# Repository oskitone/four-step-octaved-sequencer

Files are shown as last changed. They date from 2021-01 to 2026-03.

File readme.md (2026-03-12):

# Four-Step Octaved Sequencer

As featured in the blog post ["Prototype Post-Mortem: Four-Step Octaved Sequencer"](https://blog.tommy.sh/posts/prototype-post-mortem-four-step-octaved-sequencer/), these are the prototype PCB designs for a (yet to be totally finished) fun little noise toy.

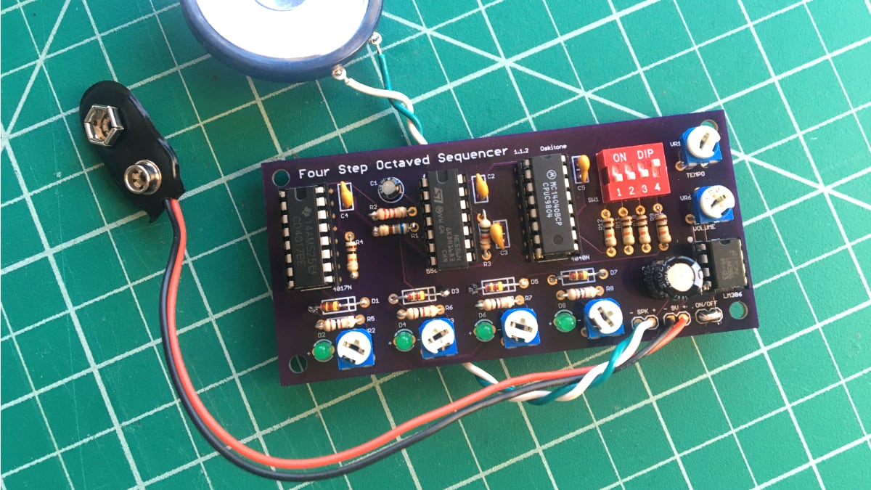
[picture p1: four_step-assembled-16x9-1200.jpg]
Four-Step Octaved Sequencer PCB assembled


The PCB and its electronics are possibly available as a [DIY electronics kit](https://www.oskitone.com/product/four-step-octaved-sequencer-kit). This repo serves as the assembly guide for the kit, as well as the EAGLE project so you can fabricate your own from scratch, should you want to!

**Demo video:** [https://vimeo.com/501110534](https://vimeo.com/501110534)  
**Order a PCB from OSH Park:** [https://oshpark.com/shared_projects/xo5nRkSm](https://oshpark.com/shared_projects/xo5nRkSm)

## Assembly guide

### Schematic

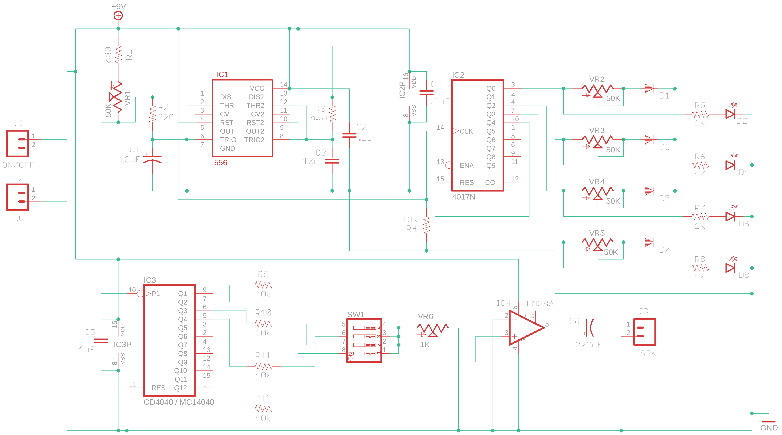
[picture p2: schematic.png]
Four Step Octaved Sequencer


### Annotated BOM

| Part | Value | Device | Marking | Purpose |
| ---- | --- | --- | --- | --- |
| C1 | 10uF | Polarized, electrolytic capacitor | | Tempo timer |
| C2 | .1uF | Ceramic capacitor | 104 | 556 IC bypass |
| C3 | 10nF | Ceramic capacitor | 103 | Pitch timer |
| C4 | .1uF | Ceramic capacitor | 104 | 4017 IC bypass |
| C5 | .1uF | Ceramic capacitor | 104 | 4040 IC bypass |
| C6 | 220uF | Polarized, electrolytic capacitor | | Amplifier |
| D1 | | Diode | | Step 1 output |
| D2 | | LED | | Step 1 indicator |
| D3 | | Diode | | Step 2 output |
| D4 | | LED | | Step 2 indicator |
| D5 | | Diode | | Step 3 output |
| D6 | | LED | | Step 3 indicator |
| D7 | | Diode | | Step 4 output |
| D8 | | LED | | Step 4 indicator |
| IC1  | 556 | 556 Dual 555 timer | | Timers for tempo (on left) and pitch (on right) |
| IC2  | 4017 | 4017 counter/divider | | Decade counter for steps |
| IC3  | 4040 | CD4040 or MC14040, 12-stage binary/ripple counter | | Divides pitch frequency into octaves |
| IC4  | 386 | LM386, low voltage audio power amplifier | | Amplifier |
| J1 | ON/OFF  | Header connection | | For external switch (not included) |
| J2 | - 9V +  | Header connection | | 9v battery snap |
| J3 | - SPK + | Header connection | | To 8ohm speaker |
| R1 | 680 | Resistor | Blue Grey Brown | Max tempo |
| R2 | 220 | Resistor | Red Red Brown | Tempo timer |
| R3 | 5.6k | Resistor | Green Blue Red | Pitch timer |
| R4 | 10k | Resistor | Brown Black Orange | Counter pulldown |
| R5 | 1K | Resistor | Brown Black Red | For step 1 LED |
| R6 | 1K | Resistor | Brown Black Red | For step 2 LED |
| R7 | 1K | Resistor | Brown Black Red | For step 3 LED |
| R8 | 1K | Resistor | Brown Black Red | For step 4 LED |
| R9 | 10k | Resistor | Brown Black Orange | Mixer for octave 1 |
| R10  | 10k | Resistor | Brown Black Orange | Mixer for octave 2 |
| R11  | 10k | Resistor | Brown Black Orange | Mixer for octave 3 |
| R12  | 10k | Resistor | Brown Black Orange | Mixer for octave 4 |
| SW1  | | 4 position SPST DIP Switch | | Octave mutes |
| VR1  | 50K | Variable resistor | 503 | Tempo |
| VR2  | 50K | Variable resistor | 503 | Step 1 pitch |
| VR3  | 50K | Variable resistor | 503 | Step 2 pitch |
| VR4  | 50K | Variable resistor | 503 | Step 3 pitch |
| VR5  | 50K | Variable resistor | 503 | Step 4 pitch |
| VR6  | 1K | Variable resistor | 102 | Volume |

Notes:

- Be sure to match polarity on electrolytic caps, diodes, and LEDs! The longer leg of the LED is positive
- The four ICs don't solder directly to the PCB. Instead, solder the included sockets, then insert ICs.
- IC3 may be marked as either CD4040 or MC14040. The two models are pin-for-pin compatible.
- The J1 (on/off) header is included for convenience if you have a switch you'd like to use. If not, short the two pads together.

### Hacking

All done? Try these ideas:

- Swap out for a bigger speaker to really hear the bass
- Increase gain on the [386](https://www.ti.com/lit/ds/symlink/lm386.pdf) with a 10uF cap between pins 1 and 8
- Try bigger pots for the step tuners
- Increase R1 for reaaalllly looongggg steeeppsssssssss
- Swap R9-12 with pots to get individual volume controls for each octave as they mix together
- The [4040](https://www.ti.com/lit/ds/symlink/cd4040b.pdf) has 12 "octave" outputs but we're only using four...

## Known issues

This PCB was last updated April 2018. In addition to the issues from the [post-mortem](https://blog.tommy.sh/posts/prototype-post-mortem-four-step-octaved-sequencer/):

- Some footprints are slightly mis-sized and require bending leads
- Volume control is linear instead of logarithmic, so range sweep isn't great
- Battery and speaker wires need relief holes to prevent breakage over time

## Version log

- **1.1.2**: Adds IC, header, and polarity labels; reorders octaves
- **1.1.1**: Adds mounting screw holes and a header for on/off switch (not included)
- **1.1**: Initial version featured in the blog post

## License

Designed by Oskitone. Please support future synth projects by purchasing from [Oskitone](https://www.oskitone.com/).

Creative Commons Attribution/Share-Alike, all text above must be included in any redistribution. See license.txt for additional details.

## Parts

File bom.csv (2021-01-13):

Part | Value | Device | Package | Description | PROD_ID | VALUE
C1 | 10uF | 10UF-POLAR-RADIAL-2.5MM-25V-20% | CPOL-RADIAL-2.5MM-5MM | 10.0µF polarized capacitors | CAP-08440 | 10uF
C2 | .1uF | 0.1UF-KIT-EZ-50V-20% | CAP-PTH-SMALL-KIT | 0.1µF ceramic capacitors | CAP-08370 | 0.1uF
C3 | 10nF | 0.1UF-KIT-EZ-50V-20% | CAP-PTH-SMALL-KIT | 0.1µF ceramic capacitors | CAP-08370 | 0.1uF
C4 | .1uF | 0.1UF-KIT-EZ-50V-20% | CAP-PTH-SMALL-KIT | 0.1µF ceramic capacitors | CAP-08370 | 0.1uF
C5 | .1uF | 0.1UF-KIT-EZ-50V-20% | CAP-PTH-SMALL-KIT | 0.1µF ceramic capacitors | CAP-08370 | 0.1uF
C6 | 220uF | 10UF-POLAR-RADIAL-2.5MM-25V-20% | CPOL-RADIAL-2.5MM-5MM | 10.0µF polarized capacitors | CAP-08440 | 10uF
D1 |  | DIODE-PTH | DIODE-1N4001 | Diode | DIO-09176 | 1A/50V/1.1V
D2 |  | LED3MM | LED_3MM | LED (Generic) | DIO-08794
D3 |  | DIODE-PTH | DIODE-1N4001 | Diode | DIO-09176 | 1A/50V/1.1V
D4 |  | LED3MM | LED_3MM | LED (Generic) | DIO-08794
D5 |  | DIODE-PTH | DIODE-1N4001 | Diode | DIO-09176 | 1A/50V/1.1V
D6 |  | LED3MM | LED_3MM | LED (Generic) | DIO-08794
D7 |  | DIODE-PTH | DIODE-1N4001 | Diode | DIO-09176 | 1A/50V/1.1V
D8 |  | LED3MM | LED_3MM | LED (Generic) | DIO-08794
IC1 | 556 | 556 | DIP14 | 556 Dual 555 timer | IC-11898 | 556
IC2 | 4017N | 4017N | DIL16 | COUNTER/DIVIDER
IC3 | CD4040 / MC14040 | 4040N | DIL16 | 12-stage binary/ripple COUNTER
IC4 | LM386 | LM386 | DIP08 | low voltage audio power amplifier | IC-10899 | LM386N
J1 | ON/OFF | CONN_02 | 1X02 | Multi connection point. Often used as Generic Header-pin footprint for 0.1 inch spaced/style header connections
J2 | - 9V + | CONN_02 | 1X02 | Multi connection point. Often used as Generic Header-pin footprint for 0.1 inch spaced/style header connections
J3 | - SPK + | CONN_02 | 1X02 | Multi connection point. Often used as Generic Header-pin footprint for 0.1 inch spaced/style header connections
R1 | 680 | 1KOHM-HORIZ-1/4W-1% | AXIAL-0.3 | 1kΩ resistor | RES-12182 | 1k
R2 | 220 | 1KOHM-HORIZ-1/4W-1% | AXIAL-0.3 | 1kΩ resistor | RES-12182 | 1k
R3 | 5.6K | 1KOHM-HORIZ-1/4W-1% | AXIAL-0.3 | 1kΩ resistor | RES-12182 | 1k
R4 | 10K | 1KOHM-HORIZ-1/4W-1% | AXIAL-0.3 | 1kΩ resistor | RES-12182 | 1k
R5 | 1K | 1KOHM-HORIZ-1/4W-1% | AXIAL-0.3 | 1kΩ resistor | RES-12182 | 1k
R6 | 1K | 1KOHM-HORIZ-1/4W-1% | AXIAL-0.3 | 1kΩ resistor | RES-12182 | 1k
R7 | 1K | 1KOHM-HORIZ-1/4W-1% | AXIAL-0.3 | 1kΩ resistor | RES-12182 | 1k
R8 | 1K | 1KOHM-HORIZ-1/4W-1% | AXIAL-0.3 | 1kΩ resistor | RES-12182 | 1k
R9 | 10k | 1KOHM-HORIZ-1/4W-1% | AXIAL-0.3 | 1kΩ resistor | RES-12182 | 1k
R10 | 10k | 1KOHM-HORIZ-1/4W-1% | AXIAL-0.3 | 1kΩ resistor | RES-12182 | 1k
R11 | 10k | 1KOHM-HORIZ-1/4W-1% | AXIAL-0.3 | 1kΩ resistor | RES-12182 | 1k
R12 | 10k | 1KOHM-HORIZ-1/4W-1% | AXIAL-0.3 | 1kΩ resistor | RES-12182 | 1k
SW1 |  | SW_DIP-4 | EDG-04 | DIP SWITCH
VR1 | 50K | POTTRIM | TRIM_POT |  | COM-00104
VR2 | 50K | POTTRIM | TRIM_POT |  | COM-00104
VR3 | 50K | POTTRIM | TRIM_POT |  | COM-00104
VR4 | 50K | POTTRIM | TRIM_POT |  | COM-00104
VR5 | 50K | POTTRIM | TRIM_POT |  | COM-00104
VR6 | 1K | POTTRIM | TRIM_POT |  | COM-00104

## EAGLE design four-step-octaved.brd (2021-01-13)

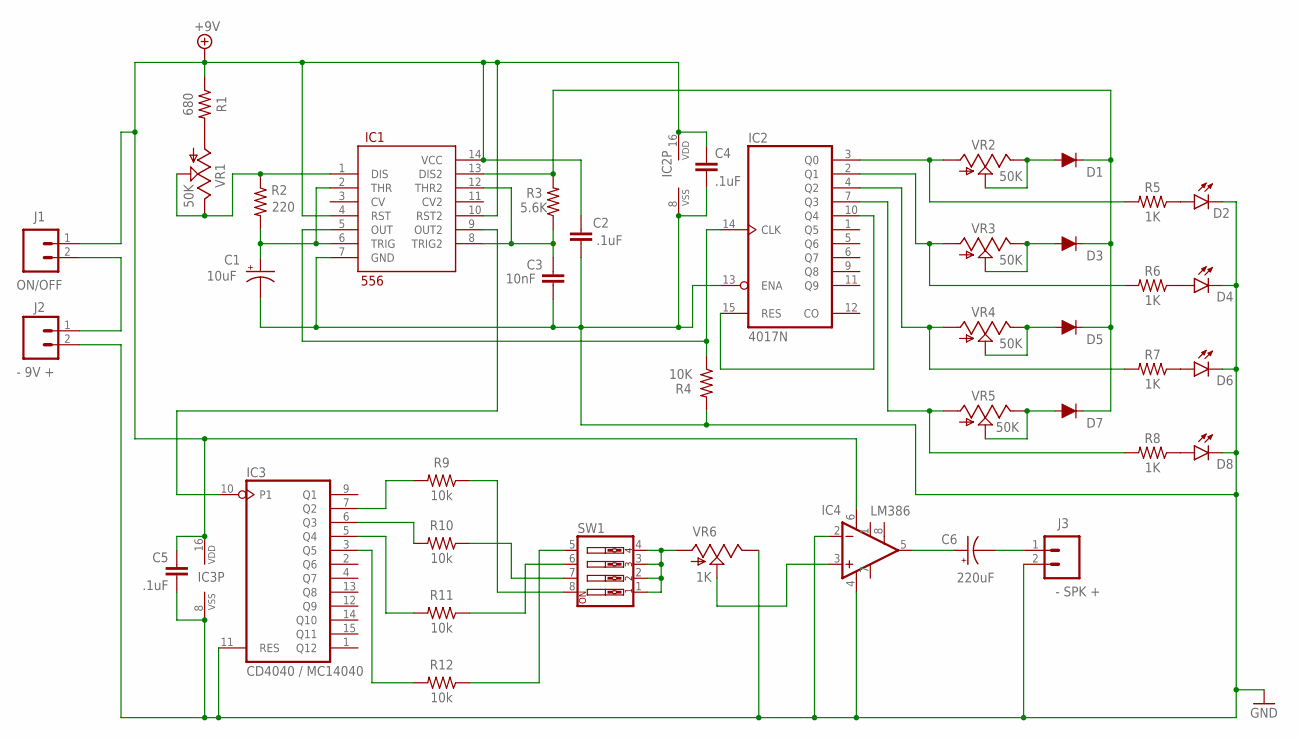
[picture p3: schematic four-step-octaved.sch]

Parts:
C1: 10uF; CPOL-RADIAL-2.5MM-5MM
C2, C4, C5: .1uF; CAP-PTH-SMALL-KIT
C3: 10nF; CAP-PTH-SMALL-KIT
C6: 220uF; CPOL-RADIAL-2.5MM-5MM
D1, D3, D5, D7: DIODE-PTH; DIODE-1N4001
D2, D4, D6, D8: LED3MM; LED_3MM
IC1: 556; DIP14
IC2: 4017N; DIL16
IC3: CD4040 / MC14040; DIL16
IC4: LM386; DIP08
J1: ON/OFF; 1X02
J2: - 9V +; 1X02
J3: - SPK +; 1X02
R1: 680; AXIAL-0.3
R2: 220; AXIAL-0.3
R3: 5.6K; AXIAL-0.3
R4: 10K; AXIAL-0.3
R5, R6, R7, R8: 1K; AXIAL-0.3
R9, R10, R11, R12: 10k; AXIAL-0.3
SW1: SW_DIP-4; EDG-04
VR1, VR2, VR3, VR4, VR5: 50K; TRIM_POT
VR6: 1K; TRIM_POT

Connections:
+9V: C2.1, C4.1, C5.1, IC1.4 (RST), IC1.10 (RST2), IC1.14 (VCC), IC2.16 (VDD), IC3.16 (VDD), IC4.6 (V+), J1.1, R1.P$1 (1)
GND: C1.2 (-), C2.2, C3.2, C4.2, C5.2, D2.K (C), D4.K (C), D6.K (C), D8.K (C), IC1.7 (GND), IC2.8 (VSS), IC2.13 (ENA), IC3.8 (VSS), IC3.11 (RES), IC4.2 (-IN), IC4.4 (V-), J2.2, J3.2, R4.P$2 (2), VR6.2 (E)
unnamed: R1.P$2 (2), VR1.3 (A)
unnamed: IC1.1 (DIS), R2.P$1 (1), VR1.1 (S), VR1.2 (E)
unnamed: C1.1 (+), IC1.2 (THR), IC1.6 (TRIG), R2.P$2 (2)
unnamed: IC2.10 (Q4), IC2.15 (RES)
unnamed: IC1.5 (OUT), IC2.14 (CLK), R4.P$1 (1)
unnamed: C3.1, IC1.8 (TRIG2), IC1.12 (THR2), R3.P$1 (1)
unnamed: IC2.3 (Q0), R5.P$2 (2), VR2.3 (A)
unnamed: IC2.2 (Q1), R6.P$2 (2), VR3.3 (A)
unnamed: IC2.4 (Q2), R7.P$2 (2), VR4.3 (A)
unnamed: IC2.7 (Q3), R8.P$2 (2), VR5.3 (A)
unnamed: D1.A, VR2.1 (S), VR2.2 (E)
unnamed: D8.A, R8.P$1 (1)
unnamed: D6.A, R7.P$1 (1)
unnamed: D4.A, R6.P$1 (1)
unnamed: D2.A, R5.P$1 (1)
unnamed: D3.A, VR3.1 (S), VR3.2 (E)
unnamed: D5.A, VR4.1 (S), VR4.2 (E)
unnamed: D7.A, VR5.1 (S), VR5.2 (E)
unnamed: D1.C, D3.C, D5.C, D7.C, IC1.13 (DIS2), R3.P$2 (2)
unnamed: IC3.7 (Q2), R9.P$2 (2)
unnamed: IC3.5 (Q4), R11.P$2 (2)
unnamed: IC3.6 (Q3), R10.P$2 (2)
unnamed: R12.P$1 (1), SW1.5
unnamed: IC4.3 (+IN), VR6.1 (S)
unnamed: IC3.3 (Q5), R12.P$2 (2)
unnamed: R11.P$1 (1), SW1.6
unnamed: C6.2 (-), J3.1
unnamed: C6.1 (+), IC4.5 (OUT)
unnamed: R10.P$1 (1), SW1.7
unnamed: R9.P$1 (1), SW1.8
unnamed: SW1.1, SW1.2, SW1.3, SW1.4, VR6.3 (A)
unnamed: J1.2, J2.1
unnamed: IC1.9 (OUT2), IC3.10 (P1)

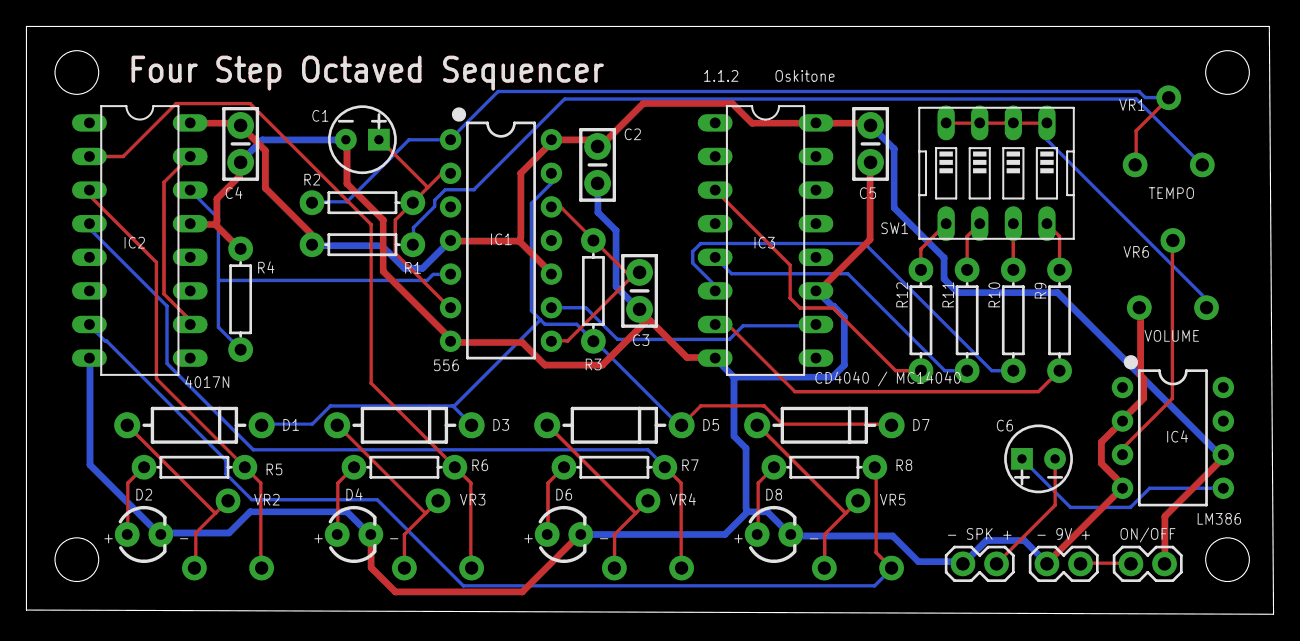
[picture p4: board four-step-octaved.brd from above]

Board: 2 copper layers, 94.3 x 44.4 mm, 40 parts (0 on the bottom side), 35 nets.

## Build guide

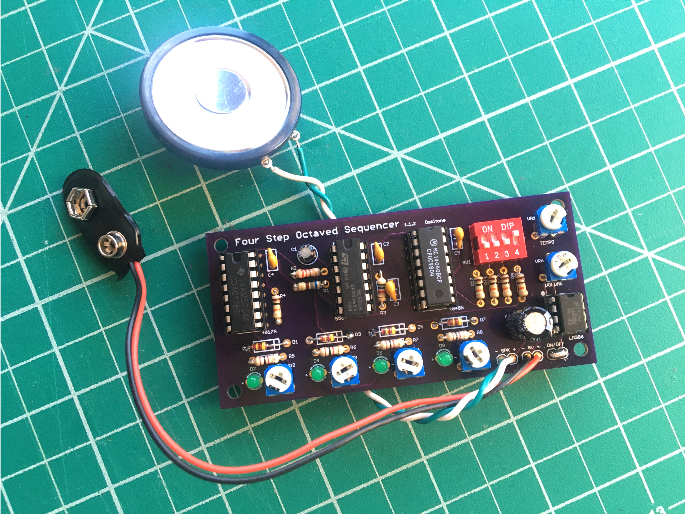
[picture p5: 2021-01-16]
four_step-assembled.jpg

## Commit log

2017-03-25 Blank schematic init
    [four-step-octaved.sch]
2017-03-26 Add 4040 and 386
    [four-step-octaved.sch]
2017-03-26 Cleanup and ERC
    [four-step-octaved.sch]
2017-03-26 Start board with 4017
    [four-step-octaved.brd]
2017-03-26 All components on board
2017-03-27 Tidier board
    [four-step-octaved.brd]
2017-03-27 Add board text and cleanup
    [four-step-octaved.brd, four-step-octaved.sch]
2017-03-27 Shorten schematic to fit on one page
    [four-step-octaved.brd, four-step-octaved.sch]
2017-03-27 Clean up board text
    [four-step-octaved.brd]
2017-03-27 Add net classes
    [four-step-octaved.brd, four-step-octaved.sch]
2017-03-28 Woof, add 1.1 board w/ switches
    [four-step-octaved_1.1.brd, four-step-octaved_1.1.sch]
2017-03-28 Reorganize board
    [four-step-octaved_1.1.brd]
2017-03-28 Fix missing 556 pin10 on both schematics
    [four-step-octaved.brd, four-step-octaved.sch, four-step-octaved_1.1.brd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]
2017-03-28 Route 1.1
    [four-step-octaved_1.1.brd]
2017-03-28 Fix text on wrong layer, only on 1.1
    [four-step-octaved_1.1.brd, four-step-octaved_1.1.sch]
2017-03-31 Fix more text, I think
    [four-step-octaved_1.1.brd]
2017-04-14 Add mounting holes, increment version to 1.1.1
    [four-step-octaved_1.1.brd]
2017-04-14 Add LED - markers
    [four-step-octaved_1.1.brd]
2017-04-14 Rename RV to VR to match waltron
    [four-step-octaved_1.1.brd, four-step-octaved_1.1.sch]
2017-04-14 Add switch
    [four-step-octaved_1.1.brd, four-step-octaved_1.1.sch]
2017-04-14 Update 386 name
    [four-step-octaved_1.1.brd, four-step-octaved_1.1.sch]
2017-04-14 Autoroute, finish
    [four-step-octaved_1.1.brd]
2018-04-04 Update to 1.1.2
    - Add header label text
    - Indicate battery and speaker polarity
    - Reverse order octave switches: low to high = left to right
    - Label ICs
    [four-step-octaved_1.1.brd, four-step-octaved_1.1.sch]
2021-01-13 Normalize versions
    * Remove previous version
    * Remove version filename prefix
    [four-step-octaved.brd, four-step-octaved.sch, four-step-octaved_1.1.brd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]
2021-01-13 Update mixing resistor values
    to what is actually in kits!
    [four-step-octaved.brd, four-step-octaved.sch]
2021-01-13 Denote alternate 4040 chip
    [four-step-octaved.brd, four-step-octaved.sch]
2021-01-13 Add BOM
    [bom.csv]
2021-01-13 Fix errant RV->VR name
    [bom.csv, four-step-octaved.brd, four-step-octaved.sch]
2021-01-15 Add readme, license, and schematic
2021-01-16 Add paper inserts design
2021-03-19 Fix errant purposes for mixer resistors
    and their references in the Hacking section
2026-03-12 Add link to order PCB

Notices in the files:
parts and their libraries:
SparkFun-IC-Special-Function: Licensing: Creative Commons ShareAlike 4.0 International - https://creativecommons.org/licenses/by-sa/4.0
